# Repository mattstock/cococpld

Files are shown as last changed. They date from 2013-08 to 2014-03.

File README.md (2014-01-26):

cococpld
========

A complete bus interface design and floppy drive emulator for the Tandy Color Computer using Arduino/AVR!

This is a combined open source/open hardware project to design a development board for a variety of 8- and 16-bit
computers, starting with the Tandy/TRS-80 Color Computer.

Videos of how these components work together are available at https://www.youtube.com/user/Greyhound716.

Directories:

firmware2 - AVR gcc project for the firmware to act as FDC and ROM programmer.
fpga - Altera Quartus project to implement the control logic for the board.
kicad - Kicad project including the schematics and board layout.
cpld - Some legacy stuff, for some earlier attempts to build the logic using small CPLDs.

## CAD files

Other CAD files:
fpga/stp1.stp

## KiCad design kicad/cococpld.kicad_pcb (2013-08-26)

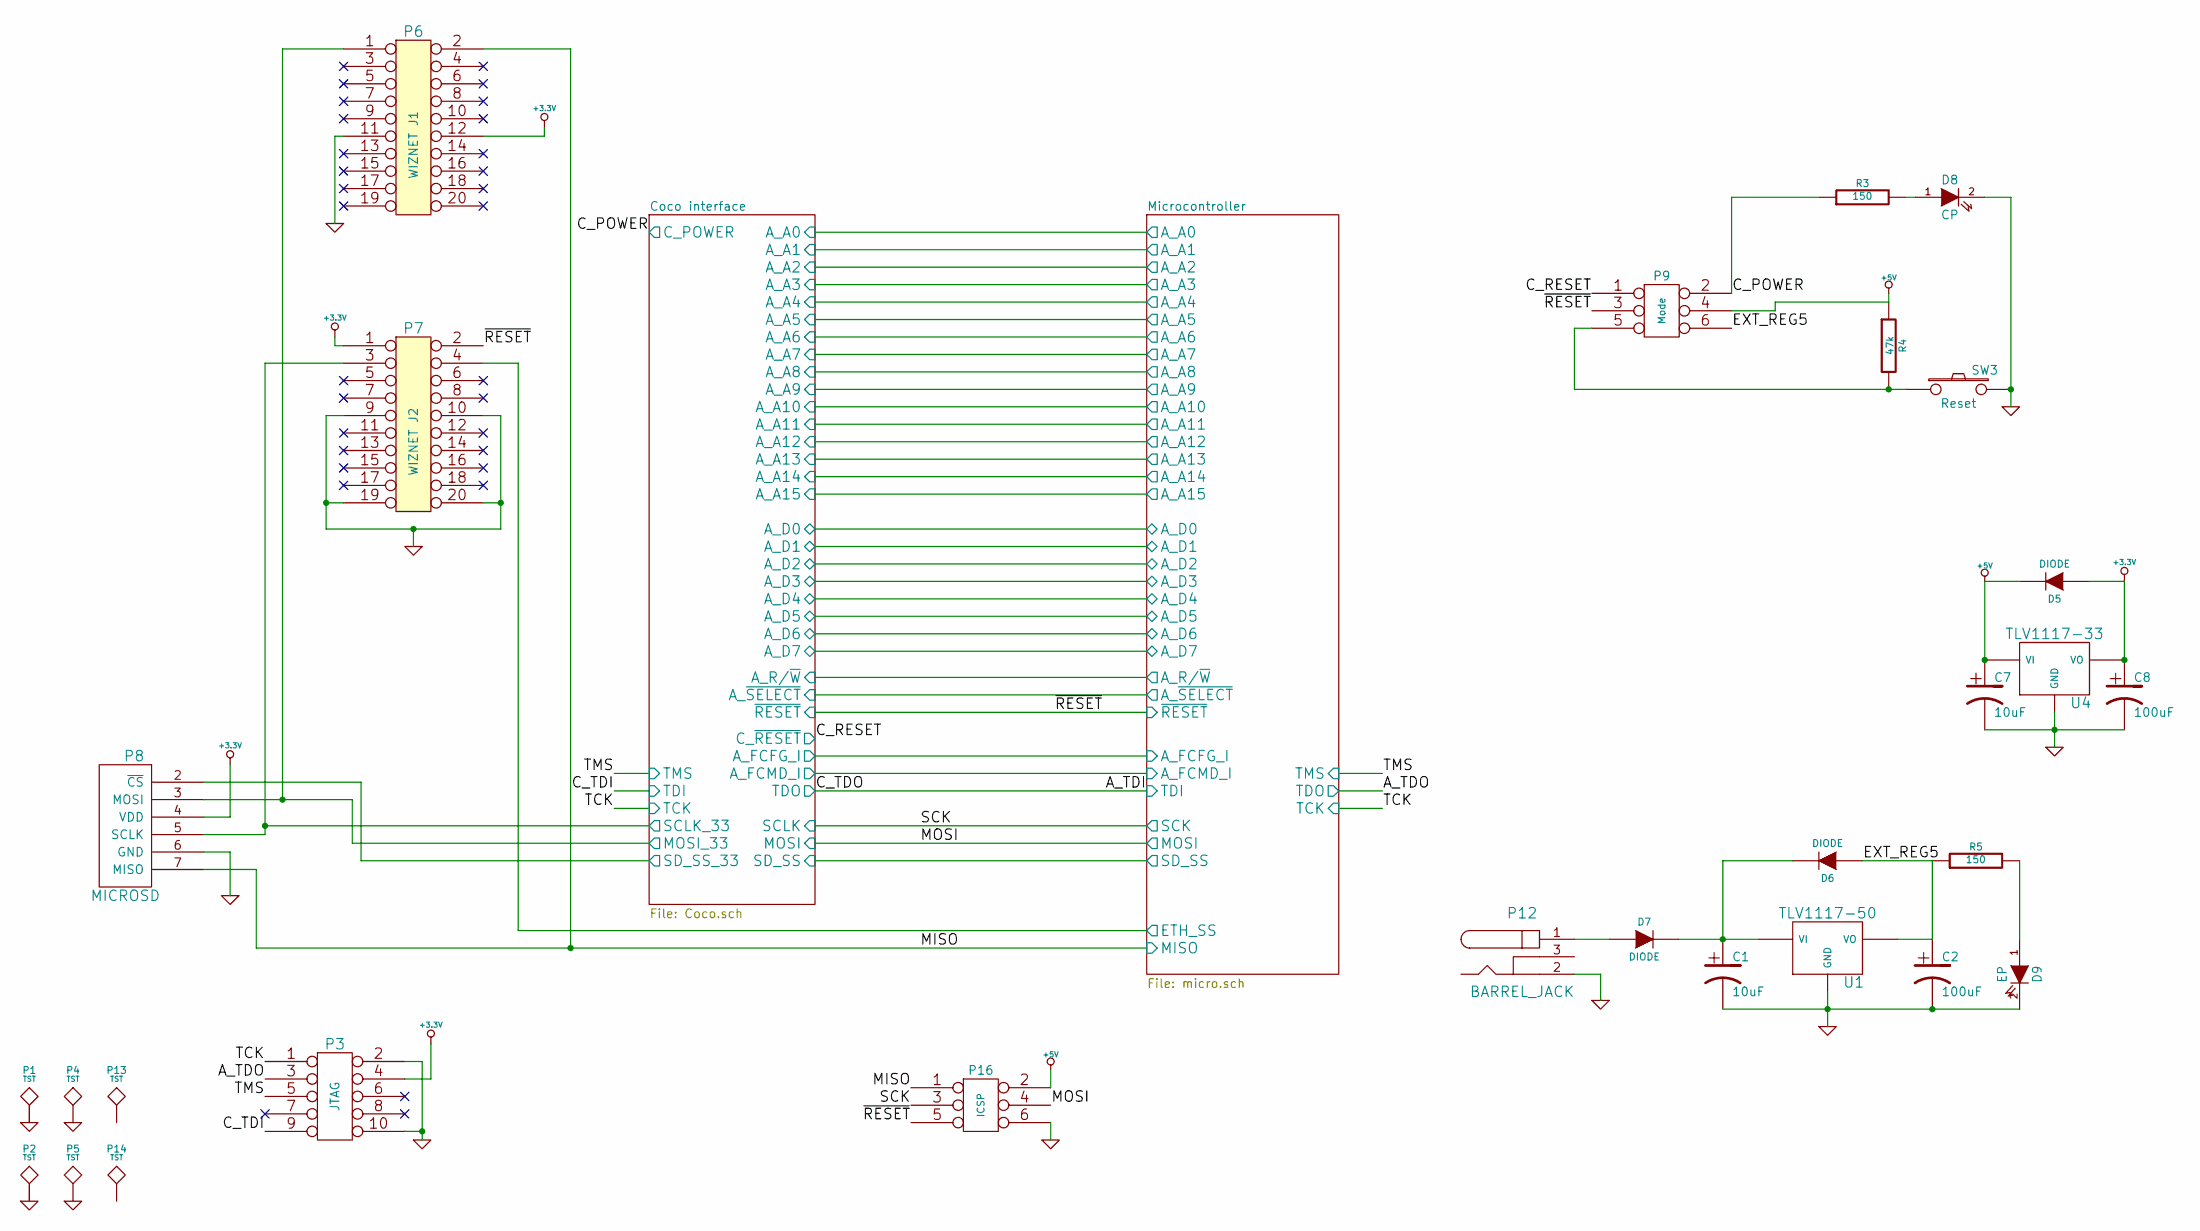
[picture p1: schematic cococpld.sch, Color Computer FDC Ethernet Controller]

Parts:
C1, C7: 10uF
C2, C8: 100uF
D5, D6, D7: DIODE
D8: CP
D9: EP
P1, P2, P4, P5, P13, P14: TST
P3: JTAG
P6: WIZNET J1
P7: WIZNET J2
P8: MICROSD
P9: Mode
P12: BARREL_JACK
P16: ICSP
R3, R5: 150
R4: 47k
SW3: Reset
U1: TLV1117-50
U4: TLV1117-33

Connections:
+3.3V: C8.1, D5.1 (A), P3.4, P6.12, P7.1, P8.4 (VDD), U4.2 (VO); also elsewhere on the board
+5V: C7.1, D5.2 (K), P9.4, P16.2, R4.1, U4.3 (VI); also elsewhere on the board
/Coco interface/C_POWER: P9.2, R3.1; also elsewhere on the board
/Coco interface/C_~RESET: P9.1; also elsewhere on the board
/Coco interface/MOSI: P16.4; also elsewhere on the board
/Coco interface/MOSI_33: P6.1, P8.3 (MOSI); also elsewhere on the board
/Coco interface/SCLK_33: P7.3, P8.5 (SCLK); also elsewhere on the board
/Coco interface/SD_SS_33: P8.2 (~CS); also elsewhere on the board
/Coco interface/TCK: P3.1; also elsewhere on the board
/Coco interface/TDI: P3.9; also elsewhere on the board
/Coco interface/TMS: P3.5; also elsewhere on the board
/Coco interface/~RESET: P7.2, P9.3, P16.5; also elsewhere on the board
/EXT_REG5: C2.1, D6.1 (A), P9.6, R5.1, U1.2 (VO)
/Microcontroller/ETH_SS: P7.4; also elsewhere on the board
/Microcontroller/MISO: P6.2, P8.7 (MISO), P16.1; also elsewhere on the board
/Microcontroller/SCK: P16.3; also elsewhere on the board
/Microcontroller/TDO: P3.3; also elsewhere on the board
GND: C1.2, C2.2, C7.2, C8.2, D8.2 (K), D9.2 (K), P1.1, P2.1, P3.2, P3.10, P4.1, P5.1, P6.11, P7.9, P7.10, P7.19, P7.20, P8.6 (GND), P12.2, P16.6, SW3.2, U1.1 (GND), U4.1 (GND); also elsewhere on the board
unnamed: C1.1, D6.2 (K), D7.2 (K), U1.3 (VI)
unnamed: D7.1 (A), P12.1
unnamed: D9.1 (A), R5.2
unnamed: D8.1 (A), R3.2
unnamed: P9.5, R4.2, SW3.1

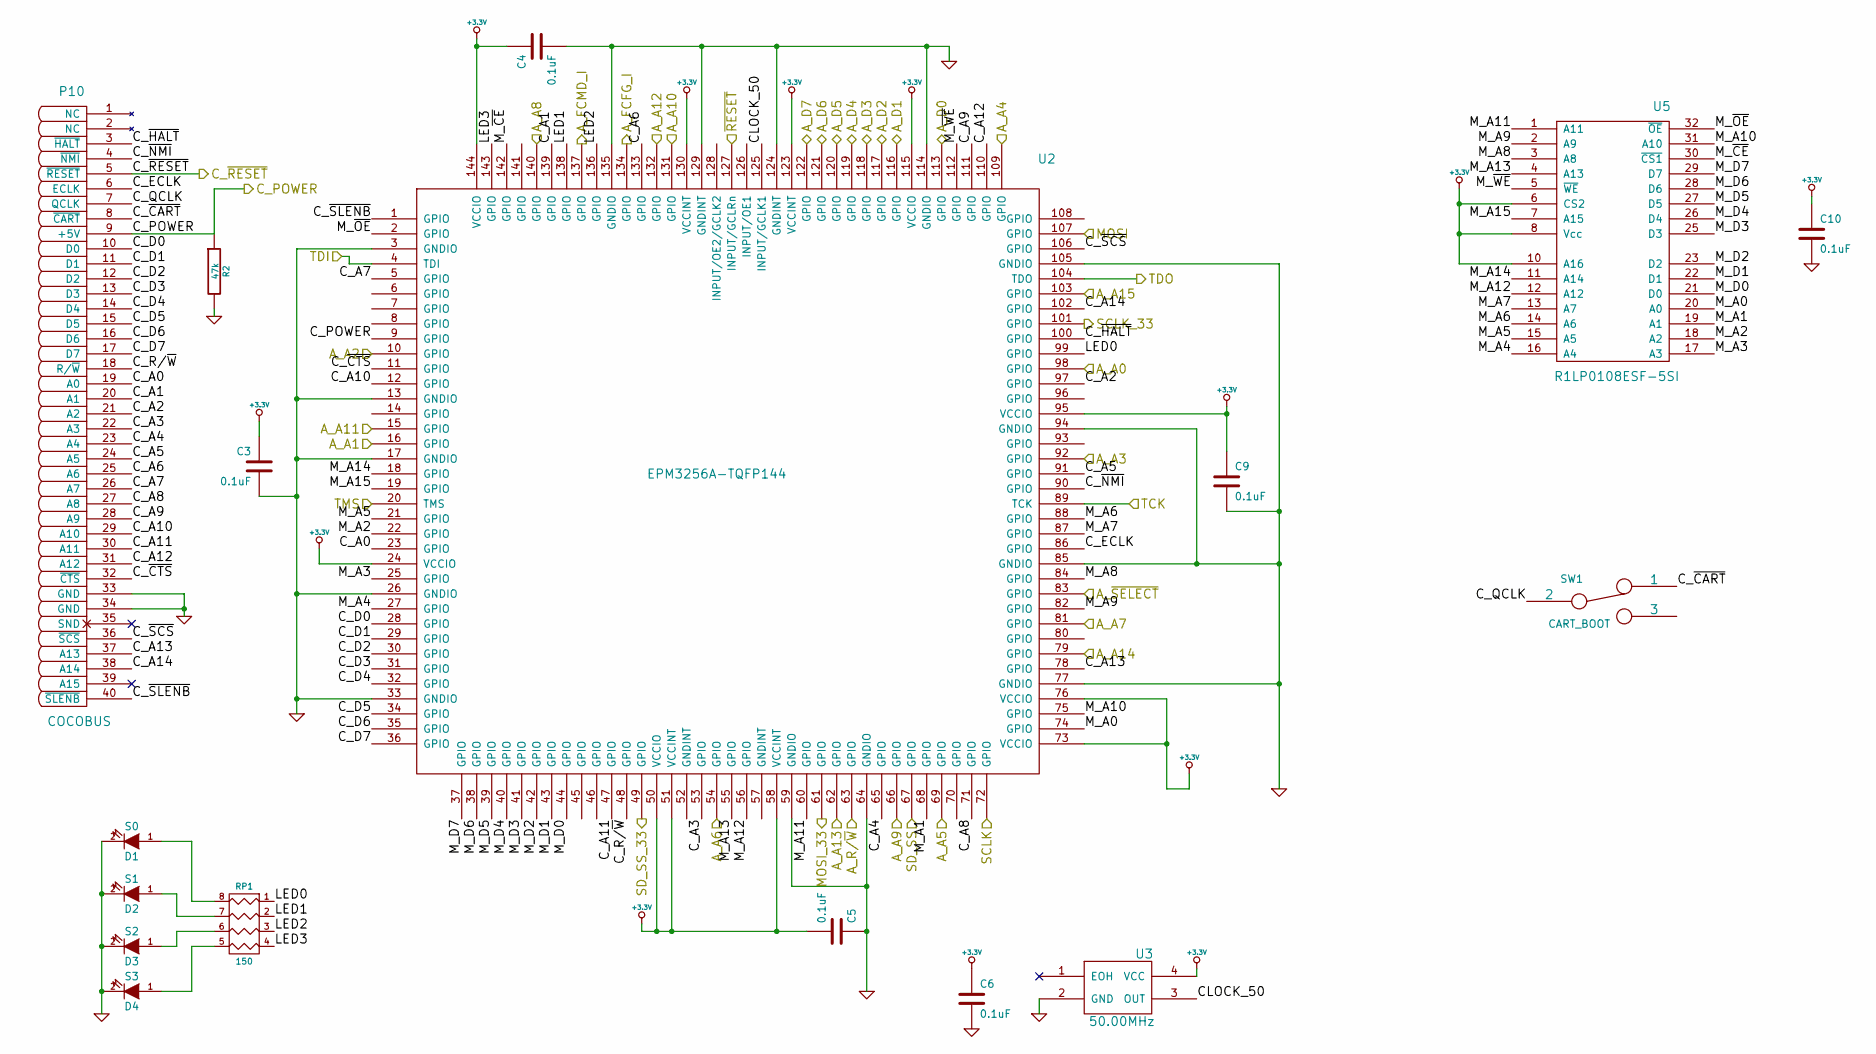
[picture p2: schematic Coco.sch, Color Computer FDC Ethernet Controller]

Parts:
C3, C4, C5, C6, C9, C10: 0.1uF
D1: S0
D2: S1
D3: S2
D4: S3
P10: COCOBUS
R2: 47k
RP1: 150
SW1: CART_BOOT
U2: EPM3256A-TQFP144
U3: 50.00MHz
U5: R1LP0108ESF-5SI

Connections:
+3.3V: C3.1, C4.1, C5.2, C6.1, C9.1, C10.1, U2.24 (VCCIO), U2.50 (VCCIO), U2.51 (VCCINT), U2.58 (VCCINT), U2.73 (VCCIO), U2.76 (VCCIO), U2.95 (VCCIO), U2.115 (VCCIO), U2.123 (VCCINT), U2.130 (VCCINT), U2.144 (VCCIO), U3.4 (VCC), U5.6 (CS2), U5.8 (Vcc), U5.10 (A16); also elsewhere on the board
/Coco interface/A_A0: U2.98 (GPIO); also elsewhere on the board
/Coco interface/A_A1: U2.16 (GPIO); also elsewhere on the board
/Coco interface/A_A2: U2.10 (GPIO); also elsewhere on the board
/Coco interface/A_A3: U2.92 (GPIO); also elsewhere on the board
/Coco interface/A_A4: U2.109 (GPIO); also elsewhere on the board
/Coco interface/A_A5: U2.69 (GPIO); also elsewhere on the board
/Coco interface/A_A6: U2.54 (GPIO); also elsewhere on the board
/Coco interface/A_A7: U2.81 (GPIO); also elsewhere on the board
/Coco interface/A_A8: U2.140 (GPIO); also elsewhere on the board
/Coco interface/A_A9: U2.66 (GPIO); also elsewhere on the board
/Coco interface/A_A10: U2.131 (GPIO); also elsewhere on the board
/Coco interface/A_A11: U2.15 (GPIO); also elsewhere on the board
/Coco interface/A_A12: U2.132 (GPIO); also elsewhere on the board
/Coco interface/A_A13: U2.62 (GPIO); also elsewhere on the board
/Coco interface/A_A14: U2.79 (GPIO); also elsewhere on the board
/Coco interface/A_A15: U2.103 (GPIO); also elsewhere on the board
/Coco interface/A_D0: U2.113 (GPIO); also elsewhere on the board
/Coco interface/A_D1: U2.116 (GPIO); also elsewhere on the board
/Coco interface/A_D2: U2.117 (GPIO); also elsewhere on the board
/Coco interface/A_D3: U2.118 (GPIO); also elsewhere on the board
/Coco interface/A_D4: U2.119 (GPIO); also elsewhere on the board
/Coco interface/A_D5: U2.120 (GPIO); also elsewhere on the board
/Coco interface/A_D6: U2.121 (GPIO); also elsewhere on the board
/Coco interface/A_D7: U2.122 (GPIO); also elsewhere on the board
/Coco interface/A_FCFG_I: U2.134 (GPIO); also elsewhere on the board
/Coco interface/A_FCMD_I: U2.137 (GPIO); also elsewhere on the board
/Coco interface/A_R/~W: U2.63 (GPIO); also elsewhere on the board
/Coco interface/A_~SELECT: U2.83 (GPIO); also elsewhere on the board
/Coco interface/CLOCK_50: U2.125 (INPUT/GCLK1), U3.3 (OUT)
/Coco interface/C_A0: P10.19 (A0), U2.23 (GPIO)
/Coco interface/C_A1: P10.20 (A1), U2.139 (GPIO)
/Coco interface/C_A2: P10.21 (A2), U2.97 (GPIO)
/Coco interface/C_A3: P10.22 (A3), U2.53 (GPIO)
/Coco interface/C_A4: P10.23 (A4), U2.65 (GPIO)
/Coco interface/C_A5: P10.24 (A5), U2.91 (GPIO)
/Coco interface/C_A6: P10.25 (A6), U2.133 (GPIO)
/Coco interface/C_A7: P10.26 (A7), U2.5 (GPIO)
/Coco interface/C_A8: P10.27 (A8), U2.71 (GPIO)
/Coco interface/C_A9: P10.28 (A9), U2.111 (GPIO)
/Coco interface/C_A10: P10.29 (A10), U2.12 (GPIO)
/Coco interface/C_A11: P10.30 (A11), U2.47 (GPIO)
/Coco interface/C_A12: P10.31 (A12), U2.110 (GPIO)
/Coco interface/C_A13: P10.37 (A13), U2.78 (GPIO)
/Coco interface/C_A14: P10.38 (A14), U2.102 (GPIO)
/Coco interface/C_D0: P10.10 (D0), U2.28 (GPIO)
/Coco interface/C_D1: P10.11 (D1), U2.29 (GPIO)
/Coco interface/C_D2: P10.12 (D2), U2.30 (GPIO)
/Coco interface/C_D3: P10.13 (D3), U2.31 (GPIO)
/Coco interface/C_D4: P10.14 (D4), U2.32 (GPIO)
/Coco interface/C_D5: P10.15 (D5), U2.34 (GPIO)
/Coco interface/C_D6: P10.16 (D6), U2.35 (GPIO)
/Coco interface/C_D7: P10.17 (D7), U2.36 (GPIO)
/Coco interface/C_ECLK: P10.6 (ECLK), U2.86 (GPIO)
/Coco interface/C_POWER: P10.9 (+5V), R2.1, U2.9 (GPIO); also elsewhere on the board
/Coco interface/C_QCLK: P10.7 (QCLK), SW1.2
/Coco interface/C_R/~W: P10.18 (R/~W), U2.48 (GPIO)
/Coco interface/C_~CART: P10.8 (~CART), SW1.1
/Coco interface/C_~CTS: P10.32 (~CTS), U2.11 (GPIO)
/Coco interface/C_~HALT: P10.3 (~HALT), U2.100 (GPIO)
/Coco interface/C_~NMI: P10.4 (~NMI), U2.90 (GPIO)
/Coco interface/C_~RESET: P10.5 (~RESET); also elsewhere on the board
/Coco interface/C_~SCS: P10.36 (~SCS), U2.106 (GPIO)
/Coco interface/C_~SLENB: P10.40 (~SLENB), U2.1 (GPIO)
/Coco interface/LED0: RP1.1, U2.99 (GPIO)
/Coco interface/LED1: RP1.2, U2.138 (GPIO)
/Coco interface/LED2: RP1.3, U2.136 (GPIO)
/Coco interface/LED3: RP1.4, U2.143 (GPIO)
/Coco interface/MOSI: U2.107 (GPIO); also elsewhere on the board
/Coco interface/MOSI_33: U2.61 (GPIO); also elsewhere on the board
/Coco interface/M_A0: U2.74 (GPIO), U5.20 (A0)
/Coco interface/M_A1: U2.68 (GPIO), U5.19 (A1)
/Coco interface/M_A2: U2.22 (GPIO), U5.18 (A2)
/Coco interface/M_A3: U2.25 (GPIO), U5.17 (A3)
/Coco interface/M_A4: U2.27 (GPIO), U5.16 (A4)
/Coco interface/M_A5: U2.21 (GPIO), U5.15 (A5)
/Coco interface/M_A6: U2.88 (GPIO), U5.14 (A6)
/Coco interface/M_A7: U2.87 (GPIO), U5.13 (A7)
/Coco interface/M_A8: U2.84 (GPIO), U5.3 (A8)
/Coco interface/M_A9: U2.82 (GPIO), U5.2 (A9)
/Coco interface/M_A10: U2.75 (GPIO), U5.31 (A10)
/Coco interface/M_A11: U2.60 (GPIO), U5.1 (A11)
/Coco interface/M_A12: U2.56 (GPIO), U5.12 (A12)
/Coco interface/M_A13: U2.55 (GPIO), U5.4 (A13)
/Coco interface/M_A14: U2.18 (GPIO), U5.11 (A14)
/Coco interface/M_A15: U2.19 (GPIO), U5.7 (A15)
/Coco interface/M_D0: U2.44 (GPIO), U5.21 (D0)
/Coco interface/M_D1: U2.43 (GPIO), U5.22 (D1)
/Coco interface/M_D2: U2.42 (GPIO), U5.23 (D2)
/Coco interface/M_D3: U2.41 (GPIO), U5.25 (D3)
/Coco interface/M_D4: U2.40 (GPIO), U5.26 (D4)
/Coco interface/M_D5: U2.39 (GPIO), U5.27 (D5)
/Coco interface/M_D6: U2.38 (GPIO), U5.28 (D6)
/Coco interface/M_D7: U2.37 (GPIO), U5.29 (D7)
/Coco interface/M_~CE: U2.142 (GPIO), U5.30 (~CS1)
/Coco interface/M_~OE: U2.2 (GPIO), U5.32 (~OE)
/Coco interface/M_~WE: U2.112 (GPIO), U5.5 (~WE)
/Coco interface/SCLK_33: U2.101 (GPIO); also elsewhere on the board
/Coco interface/SD_SS: U2.67 (GPIO); also elsewhere on the board
/Coco interface/SD_SS_33: U2.49 (GPIO); also elsewhere on the board
/Coco interface/TCK: U2.89 (TCK); also elsewhere on the board
/Coco interface/TDI: U2.4 (TDI); also elsewhere on the board
/Coco interface/TMS: U2.20 (TMS); also elsewhere on the board
/Coco interface/~RESET: U2.127 (INPUT/GCLRn); also elsewhere on the board
/Microcontroller/SCK: U2.72 (GPIO); also elsewhere on the board
/Microcontroller/TDI: U2.104 (TDO); also elsewhere on the board
GND: C3.2, C4.2, C5.1, C6.2, C9.2, C10.2, D1.2 (K), D2.2 (K), D3.2 (K), D4.2 (K), P10.33 (GND), P10.34 (GND), R2.2, U2.3 (GNDIO), U2.13 (GNDIO), U2.17 (GNDIO), U2.26 (GNDIO), U2.33 (GNDIO), U2.59 (GNDIO), U2.64 (GNDIO), U2.77 (GNDIO), U2.85 (GNDIO), U2.94 (GNDIO), U2.105 (GNDIO), U2.114 (GNDIO), U2.124 (GNDINT), U2.129 (GNDINT), U2.135 (GNDIO), U3.2 (GND), U5.24 (GND); also elsewhere on the board
unnamed: D3.1 (A), RP1.6 (R3)
unnamed: D1.1 (A), RP1.8 (R1)
unnamed: D4.1 (A), RP1.5 (R4)
unnamed: D2.1 (A), RP1.7 (R2)

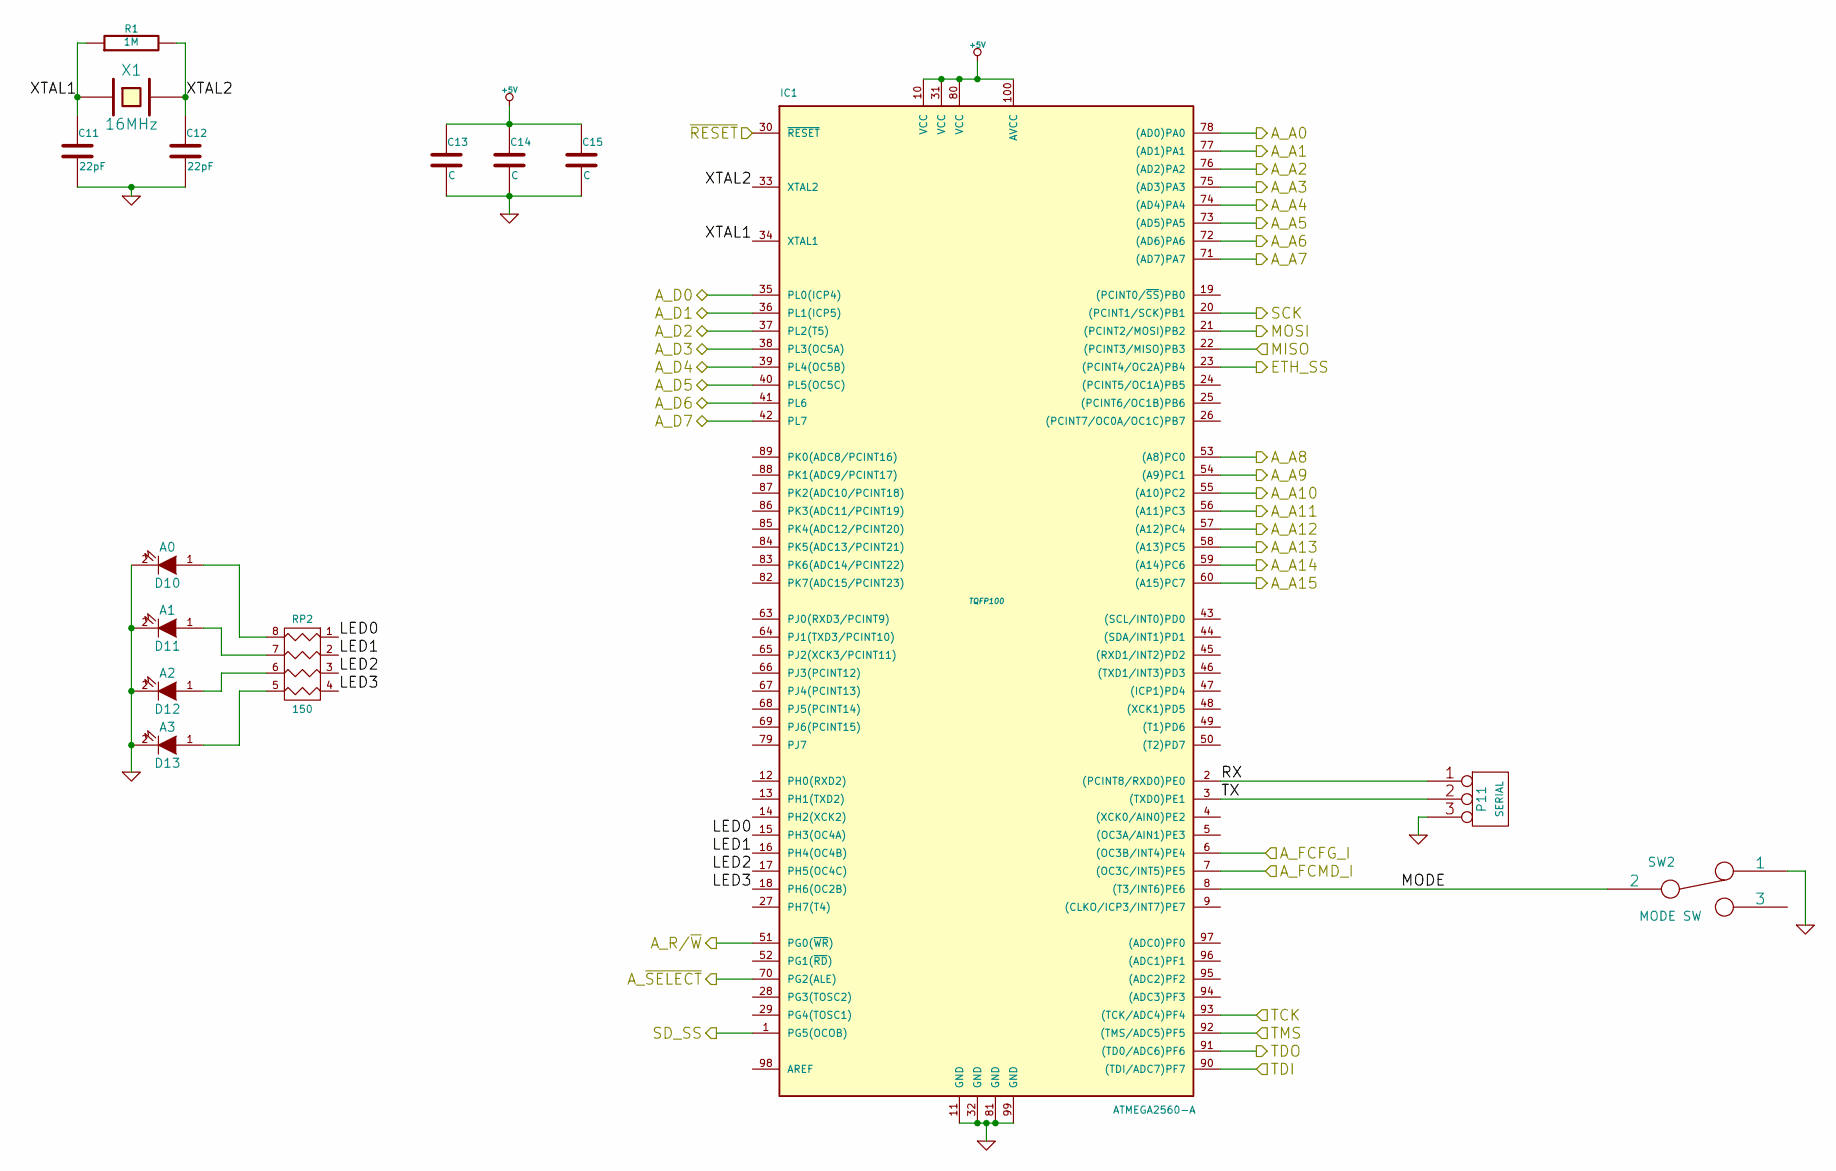
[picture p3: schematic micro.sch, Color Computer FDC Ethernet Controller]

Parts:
C11, C12: 22pF
C13, C14, C15: C
D10: A0
D11: A1
D12: A2
D13: A3
IC1: ATMEGA2560-A; TQFP100
P11: SERIAL
R1: 1M
RP2: 150
SW2: MODE SW
X1: 16MHz

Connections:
+5V: C13.1, C14.1, C15.1, IC1.10 (VCC), IC1.31 (VCC), IC1.80 (VCC), IC1.100 (AVCC); also elsewhere on the board
/Coco interface/A_A0: IC1.78 ((AD0)PA0); also elsewhere on the board
/Coco interface/A_A1: IC1.77 ((AD1)PA1); also elsewhere on the board
/Coco interface/A_A2: IC1.76 ((AD2)PA2); also elsewhere on the board
/Coco interface/A_A3: IC1.75 ((AD3)PA3); also elsewhere on the board
/Coco interface/A_A4: IC1.74 ((AD4)PA4); also elsewhere on the board
/Coco interface/A_A5: IC1.73 ((AD5)PA5); also elsewhere on the board
/Coco interface/A_A6: IC1.72 ((AD6)PA6); also elsewhere on the board
/Coco interface/A_A7: IC1.71 ((AD7)PA7); also elsewhere on the board
/Coco interface/A_A8: IC1.53 ((A8)PC0); also elsewhere on the board
/Coco interface/A_A9: IC1.54 ((A9)PC1); also elsewhere on the board
/Coco interface/A_A10: IC1.55 ((A10)PC2); also elsewhere on the board
/Coco interface/A_A11: IC1.56 ((A11)PC3); also elsewhere on the board
/Coco interface/A_A12: IC1.57 ((A12)PC4); also elsewhere on the board
/Coco interface/A_A13: IC1.58 ((A13)PC5); also elsewhere on the board
/Coco interface/A_A14: IC1.59 ((A14)PC6); also elsewhere on the board
/Coco interface/A_A15: IC1.60 ((A15)PC7); also elsewhere on the board
/Coco interface/A_D0: IC1.35 (PL0(ICP4)); also elsewhere on the board
/Coco interface/A_D1: IC1.36 (PL1(ICP5)); also elsewhere on the board
/Coco interface/A_D2: IC1.37 (PL2(T5)); also elsewhere on the board
/Coco interface/A_D3: IC1.38 (PL3(OC5A)); also elsewhere on the board
/Coco interface/A_D4: IC1.39 (PL4(OC5B)); also elsewhere on the board
/Coco interface/A_D5: IC1.40 (PL5(OC5C)); also elsewhere on the board
/Coco interface/A_D6: IC1.41 (PL6); also elsewhere on the board
/Coco interface/A_D7: IC1.42 (PL7); also elsewhere on the board
/Coco interface/A_FCFG_I: IC1.6 ((OC3B/INT4)PE4); also elsewhere on the board
/Coco interface/A_FCMD_I: IC1.7 ((OC3C/INT5)PE5); also elsewhere on the board
/Coco interface/A_R/~W: IC1.51 (PG0(~WR~)); also elsewhere on the board
/Coco interface/A_~SELECT: IC1.70 (PG2(ALE)); also elsewhere on the board
/Coco interface/MOSI: IC1.21 ((PCINT2/MOSI)PB2); also elsewhere on the board
/Coco interface/SD_SS: IC1.1 (PG5(OCOB)); also elsewhere on the board
/Coco interface/TCK: IC1.93 ((TCK/ADC4)PF4); also elsewhere on the board
/Coco interface/TMS: IC1.92 ((TMS/ADC5)PF5); also elsewhere on the board
/Coco interface/~RESET: IC1.30 (~RESET); also elsewhere on the board
/Microcontroller/ETH_SS: IC1.23 ((PCINT4/OC2A)PB4); also elsewhere on the board
/Microcontroller/LED0: IC1.15 (PH3(OC4A)), RP2.1
/Microcontroller/LED1: IC1.16 (PH4(OC4B)), RP2.2
/Microcontroller/LED2: IC1.17 (PH5(OC4C)), RP2.3
/Microcontroller/LED3: IC1.18 (PH6(OC2B)), RP2.4
/Microcontroller/MISO: IC1.22 ((PCINT3/MISO)PB3); also elsewhere on the board
/Microcontroller/MODE: IC1.8 ((T3/INT6)PE6), SW2.2
/Microcontroller/RX: IC1.2 ((PCINT8/RXD0)PE0), P11.1
/Microcontroller/SCK: IC1.20 ((PCINT1/SCK)PB1); also elsewhere on the board
/Microcontroller/TDI: IC1.90 ((TDI/ADC7)PF7); also elsewhere on the board
/Microcontroller/TDO: IC1.91 ((TD0/ADC6)PF6); also elsewhere on the board
/Microcontroller/TX: IC1.3 ((TXD0)PE1), P11.2 (PM)
/Microcontroller/XTAL1: C11.1, IC1.34 (XTAL1), R1.1, X1.1
/Microcontroller/XTAL2: C12.1, IC1.33 (XTAL2), R1.2, X1.2
GND: C11.2, C12.2, C13.2, C14.2, C15.2, D10.2 (K), D11.2 (K), D12.2 (K), D13.2 (K), IC1.11 (GND), IC1.32 (GND), IC1.81 (GND), IC1.99 (GND), P11.3, SW2.1; also elsewhere on the board
unnamed: D13.1 (A), RP2.5 (R4)
unnamed: D12.1 (A), RP2.6 (R3)
unnamed: D10.1 (A), RP2.8 (R1)
unnamed: D11.1 (A), RP2.7 (R2)

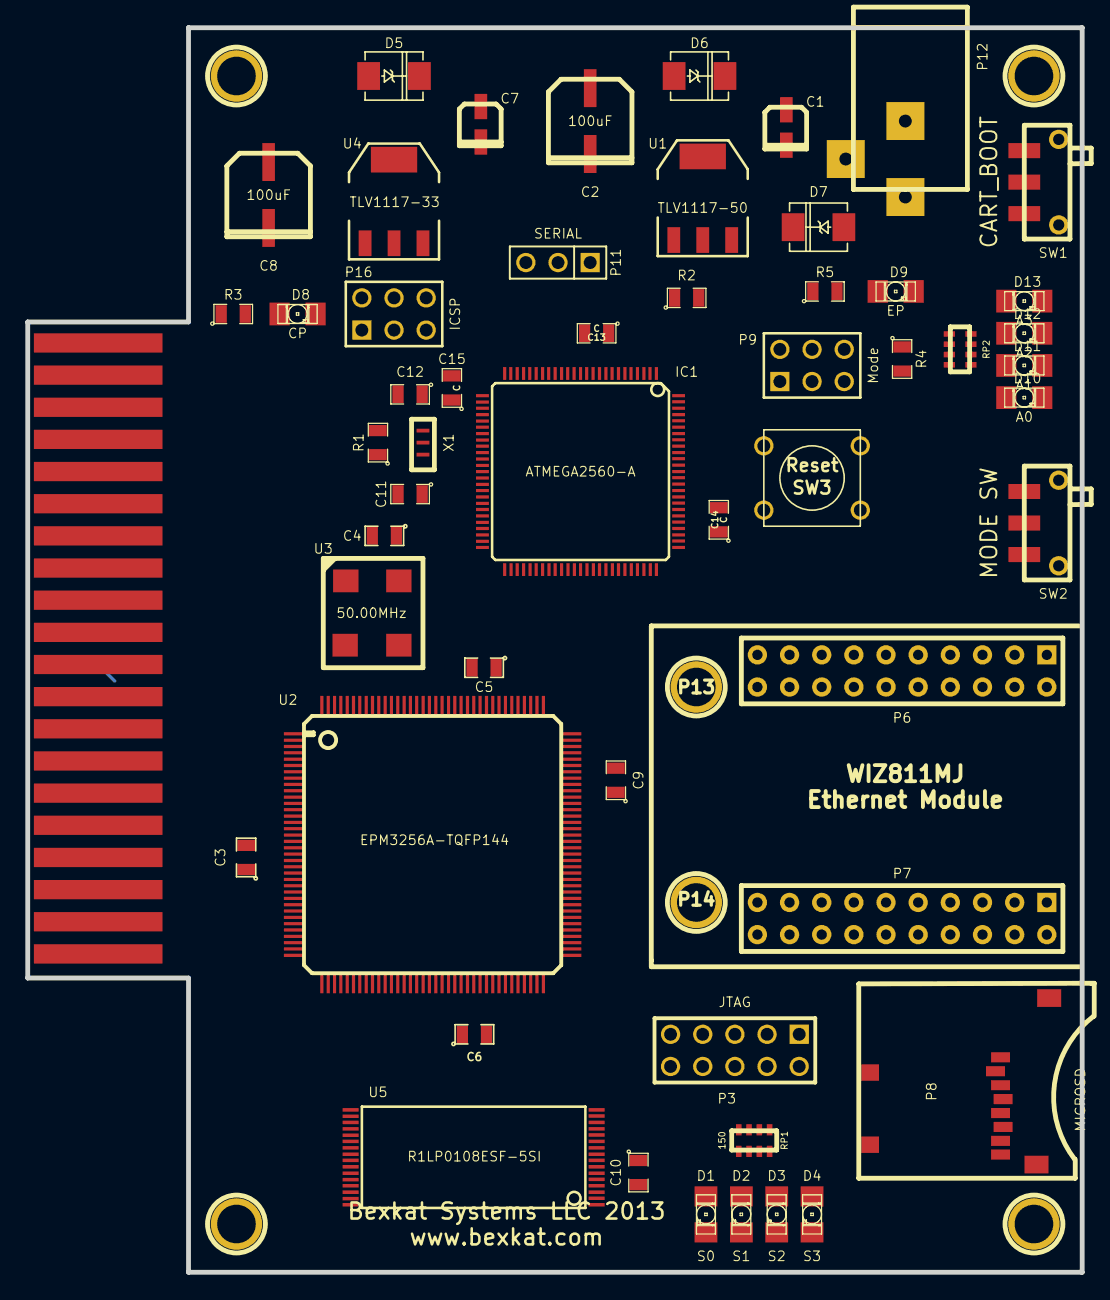
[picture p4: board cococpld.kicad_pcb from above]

Board: 2 copper layers, 83.3 x 98.3 mm, 60 parts (0 on the bottom side), 134 nets.

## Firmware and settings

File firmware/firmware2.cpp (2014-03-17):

/*
 * firmware2.cpp
 *
 * Created: 4/20/2013 1:51:38 PM
 *  Author: stock
 */ 


#include <avr/io.h>
#include <avr/interrupt.h> 
#include <Arduino.h>
#include <Ethernet.h>
#include <Adafruit_RGBLCDShield.h>
#include "firmware2.h"
#include "rom.h"
#include "fdc.h"
#include "busio.h"
#include "debug.h"

char *config[MAX_CONFIG];
//Adafruit_RGBLCDShield lcd = Adafruit_RGBLCDShield();

EthernetClient client;

void parseLine(char *line) {
  if (!strncmp("floppy0 ", line, 8)) {
    config[FLOPPY0] = (char *) malloc(13);
    strncpy(config[FLOPPY0], &(line[8]), 13);
  }
  if (!strncmp("floppy1 ", line, 8)) {
    config[FLOPPY1] = (char *) malloc(13);
    strncpy(config[FLOPPY1], &(line[8]), 13);
  }
  if (!strncmp("rom0 ", line, 5)) {
    config[ROM0] = (char *) malloc(13);
    strncpy(config[ROM0], &(line[5]), 13);
  }
  if (!strncmp("rom1 ", line, 5)) {
    config[ROM1] = (char *) malloc(13);
    strncpy(config[ROM1], &(line[5]), 13);
  }
  if (!strncmp("rom2 ", line, 5)) {
    config[ROM2] = (char *) malloc(13);
    strncpy(config[ROM2], &(line[5]), 13);
  }
  if (!strncmp("floppy-rom ", line, 11)) {
    config[ROM3] = (char *) malloc(13);
    strncpy(config[ROM3], &(line[11]),13);
  }
}

// Pull data from setup.txt if available
void loadSetup() {
  char line[30];
  uint8_t idx = 0;
  
  if (client.connect("www.bexkat.com", 80)) {
    Serial.println("connected.");
    client.println("GET /coco/setup.txt HTTP/1.1");
    client.println("Host: www.bexkat.com");
    client.println("Connection: close");
    client.println();
  } else {
    Serial.println("failed to pull setup");
    return;
  }
  
  for (int i=0; i < MAX_CONFIG; i++)
    config[i] = NULL;
  
  Serial.println("Loading config file");
  
  while (client.connected()) {
    if (client.available()) {
      line[idx++] = client.read();
      if (idx == 30) {
	Serial.print("Truncating line.");
	line[idx-1] = '\n';
      }
      if (line[idx-1] == '\r') {
	idx--;
	continue;
      }
      if (line[idx-1] == '\n') {
	line[idx-1] = '\0';
	Serial.print("Parsing = |");
	Serial.print(line);
	Serial.println("|");
	parseLine(line);
	idx = 0;
      }
    }
  }
}

void setup() {
  // Serial port for debugging output
  Serial.begin(115200);

  // Set defaults for bus enable banks
  pinMode(BANK0_ENABLE_PIN, OUTPUT);
  pinMode(BANK1_ENABLE_PIN, OUTPUT);
  pinMode(BANK2_ENABLE_PIN, OUTPUT);
  pinMode(BANK3_ENABLE_PIN, OUTPUT);
  digitalWrite(BANK0_ENABLE_PIN, LOW);
  digitalWrite(BANK1_ENABLE_PIN, HIGH); // need to tristate MISO
  digitalWrite(BANK2_ENABLE_PIN, LOW);
  digitalWrite(BANK3_ENABLE_PIN, LOW);

  // Status LED on breakout board
  pinMode(LED_PIN, OUTPUT);

  // SPI used for microSD and WizNet (if plugged in)
  SPI.begin();
  SPI.setClockDivider(SPI_CLOCK_DIV4);
  SPI.setDataMode(SPI_MODE0);
  
  // To signal we have something for the Coco
  pinMode(COCOSELECT_PIN, OUTPUT);
  digitalWrite(COCOSELECT_PIN, HIGH);

  // Configure these as interrupts eventually
  pinMode(CMDINT_PIN, INPUT);
  pinMode(CFGINT_PIN, INPUT);
  pinMode(CMDETH_PIN, INPUT);

  // Default SS pin - set to known state
  pinMode(USBSELECT_PIN, OUTPUT);
  digitalWrite(USBSELECT_PIN, HIGH);
  
  // For Wiznet module SPI select
  pinMode(ETHSELECT_PIN, OUTPUT);
  digitalWrite(ETHSELECT_PIN, HIGH);
  
  // microSD SPI select
  pinMode(SDSELECT_PIN, OUTPUT);
  digitalWrite(SDSELECT_PIN, HIGH);
  
  Serial.print("Ram: ");
  Serial.println(FreeRam());
  
  // sdcard setup
  if (!SD.begin(SDSELECT_PIN)) {
    Serial.println("microSD failed");
    //fault();
  }
  
  byte mac[] = { 0xaa, 0xbb, 0xcc, 0x00, 0x01, 0xed };
  if (Ethernet.begin(mac) == 0) {
    Serial.println("ethernet DHCP failure.");
  }

  loadSetup();

  //  uint8_t b = lcd.readButtons();
  //  if (b & BUTTON_SELECT) { // Hold select during reset will go into test mode
    // Go into the loop for the test mode
  //  Serial.println("Test mode");
  //  } else {
    Serial.println("Standard mode");
    setBank(0);
    programROM(SD.open(config[ROM0]));
    setBank(1);
    programROM(SD.open(config[ROM1]));
    setBank(2);
    programROM(SD.open(config[ROM2]));
    setBank(3);
    programROM(SD.open(config[ROM3]));
    controlPending = false;
    commandPending = false;
    attachInterrupt(0, loadConfig, FALLING);
    attachInterrupt(1, loadCommand, FALLING);
    fdc();
    //   }*/
}

extern void arduinomain(void);

void loop() {
  debugCommand();
}

int main(void) {
	arduinomain();
}

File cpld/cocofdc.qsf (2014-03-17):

# -------------------------------------------------------------------------- #
#
# Copyright (C) 1991-2012 Altera Corporation
# Your use of Altera Corporation's design tools, logic functions 
# and other software and tools, and its AMPP partner logic 
# functions, and any output files from any of the foregoing 
# (including device programming or simulation files), and any 
# associated documentation or information are expressly subject 
# to the terms and conditions of the Altera Program License 
# Subscription Agreement, Altera MegaCore Function License 
# Agreement, or other applicable license agreement, including, 
# without limitation, that your use is for the sole purpose of 
# programming logic devices manufactured by Altera and sold by 
# Altera or its authorized distributors.  Please refer to the 
# applicable agreement for further details.
#
# -------------------------------------------------------------------------- #
#
# Quartus II 64-Bit
# Version 12.1 Build 177 11/07/2012 SJ Web Edition
# Date created = 21:55:03  April 25, 2013
#
# -------------------------------------------------------------------------- #
#
# Notes:
#
# 1) The default values for assignments are stored in the file:
#		cocofdc_assignment_defaults.qdf
#    If this file doesn't exist, see file:
#		assignment_defaults.qdf
#
# 2) Altera recommends that you do not modify this file. This
#    file is updated automatically by the Quartus II software
#    and any changes you make may be lost or overwritten.
#
# -------------------------------------------------------------------------- #


set_global_assignment -name FAMILY MAX3000A
set_global_assignment -name DEVICE "EPM3256ATC144-10"
set_global_assignment -name TOP_LEVEL_ENTITY cocofdc
set_global_assignment -name ORIGINAL_QUARTUS_VERSION 12.1
set_global_assignment -name PROJECT_CREATION_TIME_DATE "21:55:03  APRIL 25, 2013"
set_global_assignment -name LAST_QUARTUS_VERSION "13.0 SP1"
set_global_assignment -name PROJECT_OUTPUT_DIRECTORY output_files
set_global_assignment -name DEVICE_FILTER_PACKAGE TQFP
set_global_assignment -name ERROR_CHECK_FREQUENCY_DIVISOR "-1"
set_global_assignment -name EDA_SIMULATION_TOOL "ModelSim-Altera (Verilog)"
set_global_assignment -name EDA_TIME_SCALE "1 ps" -section_id eda_simulation
set_global_assignment -name EDA_OUTPUT_DATA_FORMAT "VERILOG HDL" -section_id eda_simulation
set_global_assignment -name MAX7000_DEVICE_IO_STANDARD "3.3-V LVTTL"
set_global_assignment -name DEVICE_FILTER_SPEED_GRADE 10

set_global_assignment -name DEVICE_FILTER_PIN_COUNT 144
set_location_assignment PIN_125 -to clock_50
set_location_assignment PIN_37 -to sram_databus[7]
set_location_assignment PIN_38 -to sram_databus[6]
set_location_assignment PIN_39 -to sram_databus[5]
set_location_assignment PIN_40 -to sram_databus[4]
set_location_assignment PIN_41 -to sram_databus[3]
set_location_assignment PIN_42 -to sram_databus[2]
set_location_assignment PIN_43 -to sram_databus[1]
set_location_assignment PIN_44 -to sram_databus[0]
set_global_assignment -name SYNTH_TIMING_DRIVEN_SYNTHESIS OFF
set_global_assignment -name AUTO_LCELL_INSERTION ON
set_location_assignment PIN_18 -to sram_addrbus[14]
set_location_assignment PIN_55 -to sram_addrbus[13]
set_location_assignment PIN_56 -to sram_addrbus[12]
set_location_assignment PIN_60 -to sram_addrbus[11]
set_location_assignment PIN_75 -to sram_addrbus[10]
set_location_assignment PIN_82 -to sram_addrbus[9]
set_location_assignment PIN_84 -to sram_addrbus[8]
set_location_assignment PIN_87 -to sram_addrbus[7]
set_location_assignment PIN_88 -to sram_addrbus[6]
set_location_assignment PIN_21 -to sram_addrbus[5]
set_location_assignment PIN_27 -to sram_addrbus[4]
set_location_assignment PIN_25 -to sram_addrbus[3]
set_location_assignment PIN_22 -to sram_addrbus[2]
set_location_assignment PIN_68 -to sram_addrbus[1]
set_location_assignment PIN_74 -to sram_addrbus[0]
set_location_assignment PIN_142 -to sram_ce_n
set_location_assignment PIN_2 -to sram_oe_n
set_location_assignment PIN_112 -to sram_we_n
set_location_assignment PIN_19 -to sram_addrbus[15]
set_location_assignment PIN_36 -to c_databus[7]
set_location_assignment PIN_35 -to c_databus[6]
set_location_assignment PIN_34 -to c_databus[5]
set_location_assignment PIN_32 -to c_databus[4]
set_location_assignment PIN_31 -to c_databus[3]
set_location_assignment PIN_30 -to c_databus[2]
set_location_assignment PIN_29 -to c_databus[1]
set_location_assignment PIN_28 -to c_databus[0]
set_location_assignment PIN_102 -to c_addrbus[14]
set_location_assignment PIN_78 -to c_addrbus[13]
set_location_assignment PIN_110 -to c_addrbus[12]
set_location_assignment PIN_47 -to c_addrbus[11]
set_location_assignment PIN_12 -to c_addrbus[10]
set_location_assignment PIN_111 -to c_addrbus[9]
set_location_assignment PIN_71 -to c_addrbus[8]
set_location_assignment PIN_5 -to c_addrbus[7]
set_location_assignment PIN_23 -to c_addrbus[0]
set_location_assignment PIN_139 -to c_addrbus[1]
set_location_assignment PIN_97 -to c_addrbus[2]
set_location_assignment PIN_53 -to c_addrbus[3]
set_location_assignment PIN_89 -to TCK
set_location_assignment PIN_4 -to TDI
set_location_assignment PIN_104 -to TDO
set_location_assignment PIN_20 -to TMS
set_location_assignment PIN_133 -to c_addrbus[6]
set_location_assignment PIN_91 -to c_addrbus[5]
set_location_assignment PIN_65 -to c_addrbus[4]
set_location_assignment PIN_11 -to c_cts_n
set_location_assignment PIN_86 -to c_eclk
set_location_assignment PIN_100 -to c_halt_n
set_location_assignment PIN_90 -to c_nmi_n
set_location_assignment PIN_9 -to c_power
set_location_assignment PIN_48 -to c_rw
set_location_assignment PIN_106 -to c_scs_n
set_location_assignment PIN_1 -to c_slenb_n
set_location_assignment PIN_143 -to led[3]
set_location_assignment PIN_136 -to led[2]
set_location_assignment PIN_138 -to led[1]
set_location_assignment PIN_99 -to led[0]
set_location_assignment PIN_127 -to reset_n
set_global_assignment -name OPTIMIZE_HOLD_TIMING OFF
set_global_assignment -name OPTIMIZE_MULTI_CORNER_TIMING OFF
set_global_assignment -name FITTER_EFFORT "STANDARD FIT"
set_global_assignment -name VERILOG_FILE SPI_slave.v
set_global_assignment -name VERILOG_FILE cocofdc.v
set_global_assignment -name SDC_FILE cocofdc.sdc
set_location_assignment PIN_49 -to sd_ss
set_location_assignment PIN_61 -to sd_mosi
set_location_assignment PIN_101 -to sd_sclk
set_location_assignment PIN_67 -to avr_sd_ss
set_location_assignment PIN_107 -to avr_mosi
set_location_assignment PIN_72 -to avr_sclk
set_location_assignment PIN_83 -to avr_mem_ss
set_location_assignment PIN_134 -to dsk_cfg_intr
set_location_assignment PIN_137 -to dsk_cmd_intr
set_location_assignment PIN_140 -to miso

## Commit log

2013-05-05 baseline for v1.2 hardware config
    [ardbuffer.sch, cocobuf.sch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]
2013-05-05 start of integration of common bus into CPLD
    [ardbuffer.sch, cocobuf.sch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]
2013-05-06 I have no idea
    [cococpld.brd]
2013-05-07 added board routing
    [cococpld.brd]
2013-05-07 implement control logic for register memory
    [ardbuffer.sch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]
2013-05-08 start to the SPI mods
2013-05-13 fixes to een ordering
    [busio.cpp, firmware2.cpp, rom.cpp]
2013-05-23 jammed SPI stuff into CPLD
    [cocofdc.qsf, cocofdc.v]
2013-05-23 start of new schematic and board layout
    [cococpld.brd, cococpld.sch]
2013-05-24 fit all of the control code, added dirty indicator and external interrupt.
2013-05-24 revamped schematic
    [cococpld.brd, cococpld.sch]
2013-05-24 new board layout
    [cococpld.brd]
2013-05-26 updates for v1.3 board
    [cococpld.brd, cococpld.sch]
2013-05-26 minor edits
    [cococpld.sch]
2013-05-31 start to change memory and bus config
    [cococpld.sch]
2013-06-09 v1.3 hardware design is completely busted - bad SRAM footprint
2013-06-09 v1.4 HW design
    [cococpld.brd, cococpld.sch]
2013-06-09 v1.4 schematic and board with corrections
    [cococpld.brd, cococpld.sch]
2013-06-09 v1.4 verilog with correct pinout
    [cocofdc.qsf, cocofdc.v]
2013-06-15 Configured to work with MEGA ADK board and ethernet/SDcard shield for convenience. Moved all SPI select pins (lots of devices now) into busio.h
2013-06-26 fixed most of the bus interactions, CRC, etc.
    [busio.cpp, busio.h, firmware2.cpp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]
2013-07-08 refactored disk code - still working on RBF format and switching between disk formats. Reads config from setup file. CPLD code ported from FPGA but HW design still in progress. Schematic in progress,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
    [Coco.sch, ethernet.sch, micro.sch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]
2013-07-20 Virtual directory working, memory corruption problem fixed.
    [CocoDisk.cpp, CocoImage.cpp, fdc.cpp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]
2013-07-21 odd issues with support libraries now... May be due to C/C++ standard?
    [CocoDisk.cpp, CocoImage.cpp, fdc.cpp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]
2013-07-22 fixed errant missing null assignment. Need to sort out out DSKI$ works in coco
    [CocoDisk.cpp, CocoImage.cpp, fdc.cpp]
2013-07-31 added microsd and ethernet chip to design
    [Coco.sch, ethernet.sch, micro.sch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]
2013-08-04 hardware prototype for v2.0 board
    [Coco.sch, ardbuffer.sch, cocobuf.sch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]
2013-08-08 some changes
    [cococpld.sch]
2013-08-20 start of additional goodness and fixes
    [Coco.sch, micro.sch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]
2013-08-20 initial pass for v2.1 board layout
    [cococpld.kicad_pcb]
2013-08-21 initial working set for v2.0 hardware. Need to convert bus io to parallel instead of SPI.
2013-08-21 eliminated header since JTAG chaining is confirmed to work. Also drafted changes to firmware to support parallel mode I/O to CPLD instead of SPI as well as pure ROM mode.
    [Coco.sch, micro.sch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]
2013-08-22 playing with the led outputs
2013-08-22 new board route
    [cococpld.kicad_pcb]
2013-08-23 fixed memory storage instructions for fdc mode
    [busio.cpp, fdc.cpp, firmware2.cpp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]
2013-08-26 working implementation at hardware level using v2.0 HW. There are still some timing issues for the disk controller IO that need to be resolved as well as some startup issues to test. HALT is enabled 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
    [CocoDisk.cpp, busio.cpp, busio.h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]
2013-08-26 first draft of v2.1 hardware. Added some addition diagnostic leds, power indicators, and a separate SPI interface for the 5v side. Maybe add support for external LCD?
    [Coco.sch, micro.sch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]
2013-09-10 possible v2.1 design changes
    [Coco.sch, micro.sch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]
2013-09-10 make halt a wire instead of a register, and increase time delay for SRAM since the memory is 55ns. Pinout needs to change.
2013-09-13 rework for interrupt handler
    [busio.cpp, busio.h, fdc.cpp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]
2013-09-30 adding interrupt handlers, before starting to heavily optimize
2013-10-12 still not working, buy planning to start digging into interrupt handling code more completely on the Arduino end.
    [CocoDisk.cpp, busio.cpp, busio.h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]
2013-10-16 formatting and fixing a big sector read memory leak
    [CocoDisk.cpp]
2013-10-20 changed interrupts to use falling edge to better function with AVR systems
2013-10-20 recoded to hold all FDC registers in CPLD. The reaon to keep them in SRAM is gone now that we have a large CPLD. Still need to work on pin assignments and optimization.
2013-10-22 reconfig to change register mapping logic. Add atomic blocks to prevent some nasty side effects when accessing memory from avr.
    [CocoDisk.cpp, busio.cpp, busio.h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]
2013-10-23 small improvement of error message.
    [CocoDisk.cpp]
2013-10-23 Revert "small improvement of error message."
    This reverts commit 8b7cbec9f7246a75b7ae257e858cff8cba9ada3d.
    [CocoDisk.cpp]
2013-10-23 Whoops.
    Revert "Revert "small improvement of error message.""
    This reverts commit b0c30082d347fb8a64e0d93ebbbcb9c5d824ef7b.
    [CocoDisk.cpp]
2014-01-04 Back to the future. Reboot to using the SPI interface between micro and rest of the system. Using external SRAM for the ROM and non-FDC register locations. Giving up on the standalone CPLD-based solu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
    [stp1.stp]
2014-01-26 added i2c LCD library and small changes to build using new SPI interface.
2014-01-26 added basic ethernet support, as well as more debug functions.
    [stp1.stp]
2014-01-31 an experiment with delayed interrupt sends for out-of-order register assignments
2014-02-01 modified CPLD config to re-support the SPI AVR interface. This 98% works for the v2.0 board. We need to bridge MISO to one of the now available pins on the CPLD.
2014-02-09 added virtual MPI support - 4 rom address ranges, both hardware and software switched.
    [stp1.stp]
